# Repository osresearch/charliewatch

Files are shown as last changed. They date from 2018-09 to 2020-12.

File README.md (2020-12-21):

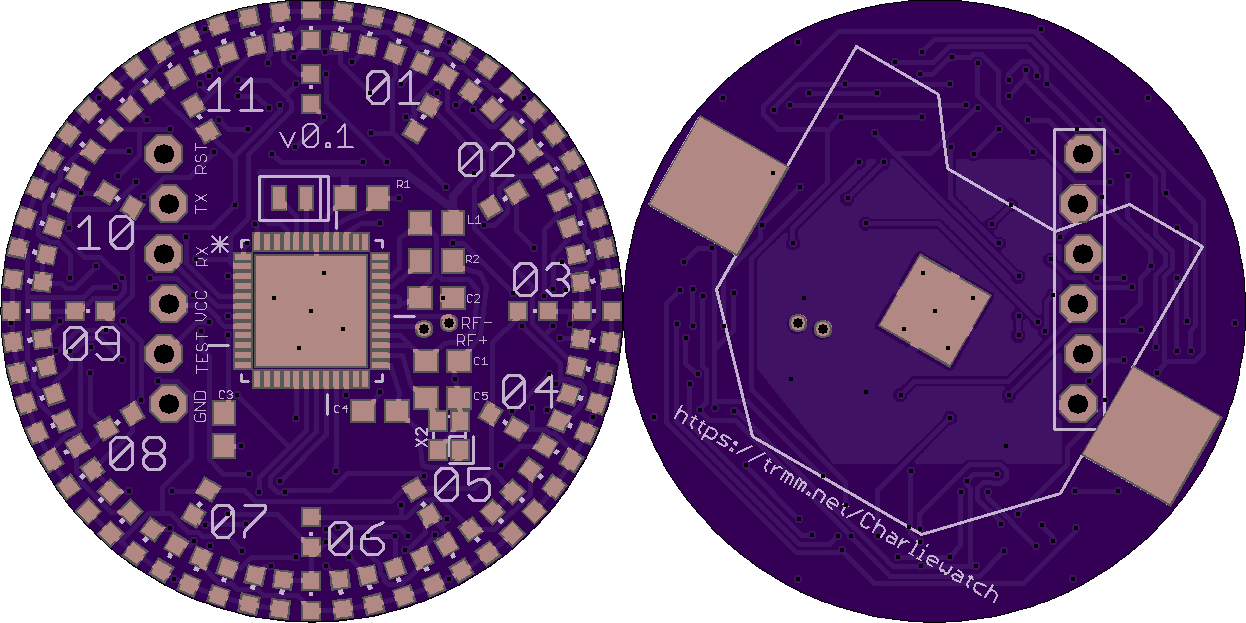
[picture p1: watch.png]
Watch rendering


"Analog" watch with 60+12 Charlieplexed LEDs. Based on Travis Goodspeed's
GoodWatch21 schematic, using the CC430F5137IRGZR CPU, which doesn't
have the LCD controller of the CC430F6xxx in the GoodWatch. There are
also pads for a six pin EZfet cable with pogopins for programming or
serial communication.

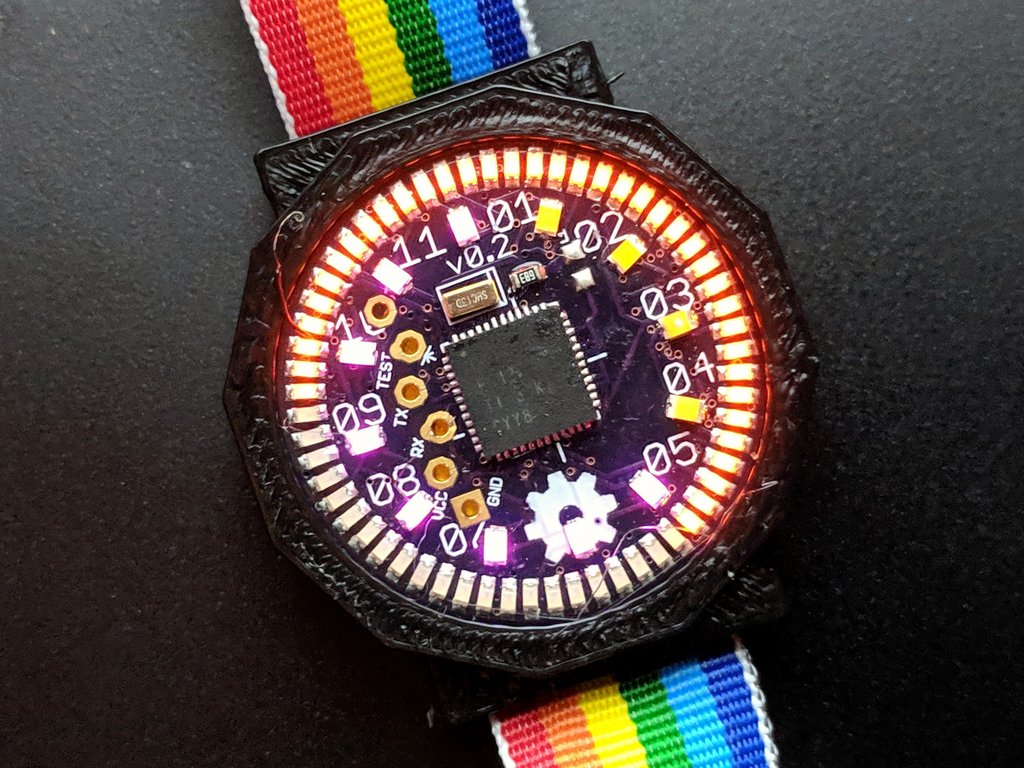
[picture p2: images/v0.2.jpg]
v0.2 board, populated

v0.2 works, although it has no radio parts.  It is exactly 1 square inch
of PCB and should fit in a 38mm or 36mm case.

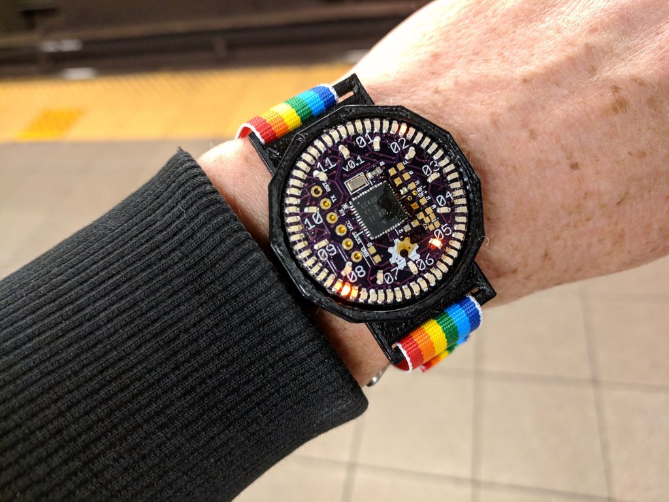
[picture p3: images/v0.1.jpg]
v0.1 board

v0.1 works, although the radio parts have not been tested.  It is a slightly
larger board and fits in a 40mm case.

[Charliewtch schematic](datasheets/charliewatch.pdf)

Building the firmware
-----

Note: some other system packages (boost libraries?) might also be needed.

First, get the toolchain (msp430-gcc):

    sudo apt install gcc-msp430 mspdebug

Then the all-important lib file (from https://www.ti.com/tool/MSPDS):

    sudo apt install libhidapi-dev
    mkdir MSPDebugStack
    wget https://software-dl.ti.com/msp430/msp430_public_sw/mcu/msp430/MSPDS/3_15_1_001/export/MSPDebugStack_OS_Package_3_15_1_1.zip

Copy in the hidapi header (WTFBBQ):

    cp /usr/include/hidapi/hidapi.h ThirdParty/include/

Copy the following into a file 'hidapi.patch', so we can use the system hidapi library:

    --- Makefile    2020-12-18 18:01:18.602942502 +0100
    +++ Makefile.new    2020-12-18 18:02:58.472096541 +0100
    @@ -123,7 +123,7 @@
     OBJS := $(patsubst %.cpp, %.o, $(SRC))
    
     all: $(BSLLIB) $(OBJS)
    -   $(CXX) $(CXXFLAGS) -shared $(OUTNAME)$(OUTPUT) -o $(OUTPUT) $(OBJS) $(HIDOBJ) $(LIBDIRS) $(BSTATIC) $(STATIC_LIBS) $(BDYNAMIC) $(LIBS)
    +   $(CXX) $(CXXFLAGS) -shared $(OUTNAME)$(OUTPUT) -o $(OUTPUT) $(OBJS) -lhidapi-libusb $(LIBDIRS) $(BSTATIC) $(STATIC_LIBS) $(BDYNAMIC) $(LIBS)
        rm -f $(STATICOUTPUT).a
        ar -rs $(STATICOUTPUT).a $(OBJS)

Then apply and make:

    patch < hidapi.patch
    make

Finally, build and flash the firmware:

    git clone https://github.com/osresearch/charliewatch.git
    cd charliewatch/firmware
    make
    export LD_LIBRARY_PATH=$LD_LIBRARY_PATH:`pwd`../../MSPDebugStack/
    mspdebug tilib "prog charliewatch.elf"

Programming cable
-----

From the top of the v0.1 board:
* RST / TDIO
* RXD on programmer
* TXD on programmer
* VCC
* TST / TCK
* GND

v0.2:
* greem
* white
* blue
* purple
* gray
* black

There is also a four-wire setup that might simplify the wiring.
Travis documents it and the power consumption here:
https://github.com/travisgoodspeed/goodwatch/wiki/EnergyTrace

Bricked Launchpad
-----

If you brick your launchpad by running Energia under Linux, it will no
longer program the Charliewatch.  The other weirdness is that `tilib`
can detect the device, but can't write to it unless run as root.

Energy Trace
----
* `libmsp430.so`: https://dlbeer.co.nz/articles/slac460y/index.html
* https://github.com/carrotIndustries/energytrace-util
* Have to update path to `MSP430.h` from the `slac/DLL430_v3/include` directory

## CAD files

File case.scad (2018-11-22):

// v0.1 board is 0.622" radius
// v0.2 board is 0.5642" radius (1 square inch)

// 3d printed bracelet (default is nato strap)
linked_bracelet = 0;

// play between the links
link_play = 1.4;

// horizontal play between the teeth
teeth_play = 0.2;

// extra spacing for the dial
dial_play = 0.4;

band_height = 4;
pin_ratio = 3/5;


module link(w,d,h,w2, last=0, first=0)
{
	render() difference() {
		intersection() {
			translate([0,0,-h/2-1])
			linear_extrude(height=h+2)
			polygon([
				[-w2/2,-(d+h+(last?h:0))/2],
				[+w2/2,-(d+h+(last?h:0))/2],
				[+w/2,+(d+h)/2],
				[-w/2,+(d+h)/2],
			]);
		union() {

			cube([w2 > w ? w2 : w,d,h], center=true);

			// positive rounded edge A1, length w2
			translate([0,d/2,0])
			rotate([0,90,0]) 
			cylinder(d=h, h=w, $fn=32, center=true);

			// positive rounded edge B2
			translate([0,-d/2,0])
			rotate([0,90,0]) 
			cylinder(d=h, h=w2, $fn=32, center=true);

			// last one has a square clasp
			if(last)
			{
				translate([0,-h,0])
				cube([w/3-2*teeth_play,h,h], center=true);

				translate([0,-h*3/2,0])
				rotate([0,90,0]) 
				cylinder(d=h, h=w/3-2*teeth_play, $fn=32, center=true);
			}
		}
		}

		// negative large rounded edge B1
		translate([w2/3/2-teeth_play,-d/2,0])
		rotate([0,90,0]) 
		cylinder(d=h+link_play, h=w2/3+4, $fn=32);

		translate([-w2/3/2+teeth_play,-d/2,0])
		rotate([0,-90,0]) 
		cylinder(d=h+link_play, h=w2/3+4, $fn=32);

		// negative large rounded edge A2
		translate([0,d/2,0])
		rotate([0,90,0]) 
		cylinder(d=h+link_play, h=w2/3+2*teeth_play, $fn=32, center=true);

		// pin hole
		translate([0,-d/2,0])
		rotate([0,90,0]) 
		cylinder(d=h*pin_ratio, h=w+2, $fn=32, center=true);

		// if this is the last one,
		if(last) {
			// make the hole open on the bottom
			translate([0,-d/2,-1])
			//rotate([20,0,0])
			cube([w,h*pin_ratio,h/2+1], center=true);

			translate([0,-d/2-h/3,0])
			rotate([0,90,0]) 
			cylinder(d=h*pin_ratio, h=w+2, $fn=32, center=true);

			translate([0,-d/2-h/3/2,0])
			//rotate([20,0,0])
			cube([w,h*pin_ratio,h*pin_ratio], center=true);
		}

		if (first) {
			// and make the clasp side even large
			translate([0,+h/3,-1])
			cube([w2/3+2*teeth_play,h,h+2], center=true);
		}


		// maybe add some fun patterns
		if(0) {
		translate([w*1/6,d/2+h/4,-1]) cylinder(d=w/4, h=h+2, $fn=7);
		translate([w*3/6,d/2-h/4,-1]) cylinder(d=w/4, h=h+2, $fn=7);
		translate([w*5/6,d/2+h/4,-1]) cylinder(d=w/4, h=h+2, $fn=7);
		}
	}

	// pin
	translate([0,d/2,0])
	rotate([0,90,0])
	cylinder(d=h*pin_ratio-2*teeth_play, h=w-2, $fn=32, center=true);
}

module case(dial,lug_offset,band_width,height)
{
render() difference()
{
	union() {
		intersection() {
		// 12-sided outside
		rotate([0,0,360/12/2]) cylinder(r=dial+2.5, h=height, $fn=12);
		// round off the corners slightly
		translate([0,0,-1]) cylinder(r=dial+2.5-0.1, h=height+2, $fn=180);
		// and round off the top slightly
		sphere(r=dial+2.5+0.8, $fn=60);
		}


		// lug
		if(linked_bracelet)
		{
			translate([+lug_offset+1,0,band_height/2])
			rotate([0,0,90])
			link(band_width, 8, band_height, w2=band_width-1);

			translate([-lug_offset-2,0,band_height/2])
			rotate([0,0,90])
			link(band_width, 8, band_height, w2=band_width);

			translate([-lug_offset,0,band_height/2])
			rotate([0,0,90])
			cube([band_width,5,band_height], center=true);
		} else {
			translate([+lug_offset,0,band_height/2])
			rotate([0,0,90])
			cube([band_width+2,8,band_height], center=true);

			translate([-lug_offset,0,band_height/2])
			rotate([0,0,90])
			cube([band_width+2,8,band_height], center=true);
		}

		// bump for button
		//translate([0,dial,height/4]) cylinder(r=3, h=height/2, $fn=30);
	}


	// tapered cylinder inside
	translate([0,0,height-1]) cylinder(r1=dial+dial_play, r2=dial-dial_play, h=1.1, $fn=60);

	// cutout for button
	translate([0,dial,1.5]) cylinder(r=3-0.1, h=2.5, $fn=30);

	// larger inside cylinder
	cylinder(r=dial+dial_play, h=height-1, $fn=180);

	// slot for strap if not using a linked bracelet
	if (!linked_bracelet)
	{
		translate([-14,0,1.5]) rotate([0,+30,0])
		cube([20,band_width+0.2,2.5], center=true);

		translate([+14,0,1.5]) rotate([0,-30,0])
		cube([20,band_width+0.2,2.5], center=true);
	}
}
}


// v0.1 case
if(0)
translate([0,25,0]) case(
	dial=0.622 * 25.4,
	lug_offset = 16,
	band_width = 22.2,
	height=8
);


// v0.2 case
band_width = 18;
band_length = 8;
band_count = round(160 / band_length / 2);

case(
	dial = 29/2, // 0.5642 * 25.4,
	lug_offset = 14,
	band_width = linked_bracelet ? band_width + band_count*0.5 : band_width,
	height = 7.5
);

if(link_braclet)
{
	for(i=[1:band_count])
	{
		translate([-i*band_length-14-2,0,band_height/2])
		rotate([0,0,90])
		link(
			band_width+(band_count-i+1)*0.5,
			band_length,
			band_height,
			band_width+(band_count-i)*0.5,
			first=(i==band_count)
		);
	}

	if(1)
	for(i=[1:band_count-1])
	{
		translate([+i*band_length+14+1,0,band_height/2])
		rotate([0,0,90])
		link(
			band_width + (band_count-i)*0.5,
			band_length,
			band_height,
			band_width + (band_count-i-1)*0.5,
			last=(i==band_count-1)
		);
	}
}

%translate([0,20,0]) cube([190,1,1], center=true);

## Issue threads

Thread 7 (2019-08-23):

Charlieboard-bicolor brd file

salmansheikh, 2019-08-23:
Hello,

When I open it in Eagle, it says Dont forget change dimension circle to 0.5642. Do I need to modify the pcb? And when I uploaded the 2 layer board to osh-park, I got this. Is this okay to order and will work correctly?
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

pomeroyb, 2019-08-25:
I believe that the file you've uploaded won't work. You'll need to use either "routed.brd" or "routed-norf.brd" for a file that works I think.

Opening "charliewatch-bicolor.brd" shows that there are still a lot of airwires in that file. Looking at the photo you've attached -- it definitely looks like it's missing traces.

Disclaimer: I'm not the creator of these files, i've just been playing with them for the past day or so.

salmansheikh, 2019-08-25:
Oh no. I uploaded and ordered the board from osh-Park. Oh well $6.45 for 3
coasters. 😂. I will do it again.

On Sun, Aug 25, 2019 at 1:36 AM Brandon Pomeroy <notifications@github.com>
wrote:

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
--
Even a Smile is charity :)
- Prophet Muhammad

salmansheikh, 2019-08-25:
What is the difference between the routed and routed-norf in capability? Are you using any of the rf capabilities of the chip?

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

pomeroyb, 2019-08-26:
The routed version breaks out pins for the wireless antenna. The routed-norf version doesn’t, but they are otherwise identical iirc.

I’m not personally using any rf stuff in my version, I don’t think it’s that interesting. :)

salmansheikh, 2019-09-01:
The LEDS making the seconds or minutes vs hours look like 2 different sizes. Also, what are the crystal values..I don't see them on the schematic.

pomeroyb, 2019-09-01:
The LEDs on the routed boards are all 0603 surface mount LEDs. On the bicolor file, the minute LEDs are
https://www.digikey.com/product-detail/en/kingbright/APHB1608SYKSURKC/754-1855-1-ND/4977027

The crystal used is (I believe)
https://www.digikey.com/product-detail/en/iqd-frequency-products/LFXTAL050789REEL/1923-1583-1-ND/8634325

@osresearch could you confirm that that is the proper crystal?

MarkJB, 2019-09-23:
I've ordered some PCBs as a fun group build for the local maker space and am starting to order the components but I'm also stuck on the xtal and would appreciate confirmation of the part used.

salmansheikh, 2019-09-25:
The crystal is in the email above but also available from Mouser at

https://www.mouser.com/ProductDetail/449-LFXTAL050789CUTT

And repeated here from the previous post by pomeroyb on this issue:

https://www.digikey.com/product-detail/en/iqd-frequency-products/LFXTAL050789REEL/1923-1583-1-ND/8634325

I found LEDs to be cheaper at mouser.  I have 3 components here (LED, chip and crystal). Need to get the rest of the passives from the schematic and add them. Price is around $38 for 3 so far, it was like $58 for equivalent from digikey using inolux LEDs..

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

salmansheikh, 2019-09-25:
Also, there is no part value for C1-C4 (size 0603 is all that is shown in the charliewatch.sch which I think corresponds with routed.brd.
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

osresearch, 2019-09-25:
Sorry for not catching this one earlier -- I just received a notification for the recent comment, but had missed the earlier questions.

The bi-color board is not finished.  I haven't found decent bicolor 0603 LEDs, so that part of the project stopped.  The routed-norf is the most recent and works well.

The crystal I used is https://www.digikey.com/product-detail/en/ABS07-120-32.768KHZ-T/535-11937-1-ND/3724046

And the orange LEDs are 2V forward voltage, 160 millicandela https://www.digikey.com/product-detail/en/LO+Q976-PS-25-0-20-R18/475-2486-1-ND/1802613

I'm a horrible EE and there are no caps on the board, just a pull up resistor on the reset line.

salmansheikh, 2019-09-25:
I had the routed.brd built. How is that different from the norf version?

osresearch, 2019-09-25:
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

The v0.1 (`routed.brd`) is slightly larger than the v0.2 (`routed-norf.brd`) and doesn't have a button on the bottom.  The RF parts were never assembled or tested.

For time and mode setting you can use a jumper wire on the RX pin.  There is a define in `button.c` to remap it as the input button: https://github.com/osresearch/charliewatch/blob/master/firmware/button.c#L11

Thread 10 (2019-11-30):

Build errors: BUILDTIME & BUILDSEC undeclared here (not in function)

MarkJB, 2019-11-30:
I'm seeing build errors in the latest Code Composer Studio and the GNU v8.3.0.16 compiler on Win10.

I'll keep trying to figure this out, but any suggestions or pointers appreciated.

Build output:

```
**** Build of configuration Release__GNU for project Charliewatch ****

"D:\\Apps\\ti\\cc920\\ccs\\utils\\bin\\gmake" -k -j 8 all -O

Building file: "../buildtime.c"
Invoking: GNU Compiler
"D:/Apps/ti/cc920/ccs/tools/compiler/msp430-gcc-8.3.0.16_win32/bin/msp430-elf-gcc-8.3.0.exe" -c -mmcu=cc430f5137 -mhwmult=f5series -I"D:/Apps/ti/cc920/ccs/ccs_base/msp430/include_gcc" -I"D:/Code/charliewatch/firmware" -I"D:/Apps/ti/cc920/ccs/tools/compiler/msp430-gcc-8.3.0.16_win32/msp430-elf/include" -Os -Wall -MMD -MP -MF"buildtime.d" -MT"buildtime.o"   -o"buildtime.o" "../buildtime.c"
subdir_rules.mk:9: recipe for target 'buildtime.o' failed
../buildtime.c:4:33: error: 'BUILDTIME' undeclared here (not in a function)
 const uint8_t romsavetime[] = { BUILDTIME };
                                 ^~~~~~~~~
../buildtime.c:5:28: error: 'BUILDSEC' undeclared here (not in a function)
 const uint32_t buildtime = BUILDSEC;
                            ^~~~~~~~
../buildtime.c:5:28: warning: initialization of 'uint32_t' {aka 'const long unsigned int'} from 'const uint8_t *' {aka 'const unsigned char *'} makes integer from pointer without a cast [-Wint-conversion]
../buildtime.c:5:28: error: initializer element is not constant
gmake: *** [buildtime.o] Error 1
Building file: "../adc.c"
Invoking: GNU Compiler
"D:/Apps/ti/cc920/ccs/tools/compiler/msp430-gcc-8.3.0.16_win32/bin/msp430-elf-gcc-8.3.0.exe" -c -mmcu=cc430f5137 -mhwmult=f5series -I"D:/Apps/ti/cc920/ccs/ccs_base/msp430/include_gcc" -I"D:/Code/charliewatch/firmware" -I"D:/Apps/ti/cc920/ccs/tools/compiler/msp430-gcc-8.3.0.16_win32/msp430-elf/include" -Os -Wall -MMD -MP -MF"adc.d" -MT"adc.o"   -o"adc.o" "../adc.c"
Finished building: "../adc.c"

Building file: "../button.c"
Invoking: GNU Compiler
"D:/Apps/ti/cc920/ccs/tools/compiler/msp430-gcc-8.3.0.16_win32/bin/msp430-elf-gcc-8.3.0.exe" -c -mmcu=cc430f5137 -mhwmult=f5series -I"D:/Apps/ti/cc920/ccs/ccs_base/msp430/include_gcc" -I"D:/Code/charliewatch/firmware" -I"D:/Apps/ti/cc920/ccs/tools/compiler/msp430-gcc-8.3.0.16_win32/msp430-elf/include" -Os -Wall -MMD -MP -MF"button.d" -MT"button.o"   -o"button.o" "../button.c"
Finished building: "../button.c"

Building file: "../animation.c"
Invoking: GNU Compiler
"D:/Apps/ti/cc920/ccs/tools/compiler/msp430-gcc-8.3.0.16_win32/bin/msp430-elf-gcc-8.3.0.exe" -c -mmcu=cc430f5137 -mhwmult=f5series -I"D:/Apps/ti/cc920/ccs/ccs_base/msp430/include_gcc" -I"D:/Code/charliewatch/firmware" -I"D:/Apps/ti/cc920/ccs/tools/compiler/msp430-gcc-8.3.0.16_win32/msp430-elf/include" -Os -Wall -MMD -MP -MF"animation.d" -MT"animation.o"   -o"animation.o" "../animation.c"
Finished building: "../animation.c"

Building file: "../clockset.c"
Invoking: GNU Compiler
"D:/Apps/ti/cc920/ccs/tools/compiler/msp430-gcc-8.3.0.16_win32/bin/msp430-elf-gcc-8.3.0.exe" -c -mmcu=cc430f5137 -mhwmult=f5series -I"D:/Apps/ti/cc920/ccs/ccs_base/msp430/include_gcc" -I"D:/Code/charliewatch/firmware" -I"D:/Apps/ti/cc920/ccs/tools/compiler/msp430-gcc-8.3.0.16_win32/msp430-elf/include" -Os -Wall -MMD -MP -MF"clockset.d" -MT"clockset.o"   -o"clockset.o" "../clockset.c"
Finished building: "../clockset.c"

Building file: "../led.c"
Invoking: GNU Compiler
"D:/Apps/ti/cc920/ccs/tools/compiler/msp430-gcc-8.3.0.16_win32/bin/msp430-elf-gcc-8.3.0.exe" -c -mmcu=cc430f5137 -mhwmult=f5series -I"D:/Apps/ti/cc920/ccs/ccs_base/msp430/include_gcc" -I"D:/Code/charliewatch/firmware" -I"D:/Apps/ti/cc920/ccs/tools/compiler/msp430-gcc-8.3.0.16_win32/msp430-elf/include" -Os -Wall -MMD -MP -MF"led.d" -MT"led.o"   -o"led.o" "../led.c"
Finished building: "../led.c"

Building file: "../main.c"
Invoking: GNU Compiler
"D:/Apps/ti/cc920/ccs/tools/compiler/msp430-gcc-8.3.0.16_win32/bin/msp430-elf-gcc-8.3.0.exe" -c -mmcu=cc430f5137 -mhwmult=f5series -I"D:/Apps/ti/cc920/ccs/ccs_base/msp430/include_gcc" -I"D:/Code/charliewatch/firmware" -I"D:/Apps/ti/cc920/ccs/tools/compiler/msp430-gcc-8.3.0.16_win32/msp430-elf/include" -Os -Wall -MMD -MP -MF"main.d" -MT"main.o"   -o"main.o" "../main.c"
Finished building: "../main.c"

Building file: "../power.c"
Invoking: GNU Compiler
"D:/Apps/ti/cc920/ccs/tools/compiler/msp430-gcc-8.3.0.16_win32/bin/msp430-elf-gcc-8.3.0.exe" -c -mmcu=cc430f5137 -mhwmult=f5series -I"D:/Apps/ti/cc920/ccs/ccs_base/msp430/include_gcc" -I"D:/Code/charliewatch/firmware" -I"D:/Apps/ti/cc920/ccs/tools/compiler/msp430-gcc-8.3.0.16_win32/msp430-elf/include" -Os -Wall -MMD -MP -MF"power.d" -MT"power.o"   -o"power.o" "../power.c"
Finished building: "../power.c"

Building file: "../rtc.c"
Invoking: GNU Compiler
"D:/Apps/ti/cc920/ccs/tools/compiler/msp430-gcc-8.3.0.16_win32/bin/msp430-elf-gcc-8.3.0.exe" -c -mmcu=cc430f5137 -mhwmult=f5series -I"D:/Apps/ti/cc920/ccs/ccs_base/msp430/include_gcc" -I"D:/Code/charliewatch/firmware" -I"D:/Apps/ti/cc920/ccs/tools/compiler/msp430-gcc-8.3.0.16_win32/msp430-elf/include" -Os -Wall -MMD -MP -MF"rtc.d" -MT"rtc.o"   -o"rtc.o" "../rtc.c"
Finished building: "../rtc.c"

Building file: "../ucs.c"
Invoking: GNU Compiler
"D:/Apps/ti/cc920/ccs/tools/compiler/msp430-gcc-8.3.0.16_win32/bin/msp430-elf-gcc-8.3.0.exe" -c -mmcu=cc430f5137 -mhwmult=f5series -I"D:/Apps/ti/cc920/ccs/ccs_base/msp430/include_gcc" -I"D:/Code/charliewatch/firmware" -I"D:/Apps/ti/cc920/ccs/tools/compiler/msp430-gcc-8.3.0.16_win32/msp430-elf/include" -Os -Wall -MMD -MP -MF"ucs.d" -MT"ucs.o"   -o"ucs.o" "../ucs.c"
Finished building: "../ucs.c"

Building file: "../stopwatch.c"
Invoking: GNU Compiler
"D:/Apps/ti/cc920/ccs/tools/compiler/msp430-gcc-8.3.0.16_win32/bin/msp430-elf-gcc-8.3.0.exe" -c -mmcu=cc430f5137 -mhwmult=f5series -I"D:/Apps/ti/cc920/ccs/ccs_base/msp430/include_gcc" -I"D:/Code/charliewatch/firmware" -I"D:/Apps/ti/cc920/ccs/tools/compiler/msp430-gcc-8.3.0.16_win32/msp430-elf/include" -Os -Wall -MMD -MP -MF"stopwatch.d" -MT"stopwatch.o"   -o"stopwatch.o" "../stopwatch.c"
Finished building: "../stopwatch.c"

Building file: "../rtcasm.S"
Invoking: GNU Compiler
"D:/Apps/ti/cc920/ccs/tools/compiler/msp430-gcc-8.3.0.16_win32/bin/msp430-elf-gcc-8.3.0.exe" -c -mmcu=cc430f5137 -mhwmult=f5series -I"D:/Apps/ti/cc920/ccs/ccs_base/msp430/include_gcc" -I"D:/Code/charliewatch/firmware" -I"D:/Apps/ti/cc920/ccs/tools/compiler/msp430-gcc-8.3.0.16_win32/msp430-elf/include" -Os -Wall -MMD -MP -MF"rtcasm.d" -MT"rtcasm.o" -x assembler-with-cpp  -o"rtcasm.o" "../rtcasm.S"
../rtcasm.S: Assembler messages:
../rtcasm.S:60: Warning: a NOP might be needed here, before an interrupt enable instruction
../rtcasm.S:61: Warning: a NOP might be needed here, after an interrupt enable instruction
../rtcasm.S:85: Warning: a NOP might be needed here, after an interrupt enable instruction
../rtcasm.S:120: Warning: a NOP might be needed here, after an interrupt enable instruction
../rtcasm.S:141: Warning: a NOP might be needed here, after an interrupt enable instruction
../rtcasm.S:164: Warning: a NOP might be needed here, after an interrupt enable instruction
../rtcasm.S:185: Warning: a NOP might be needed here, after an interrupt enable instruction
../rtcasm.S:208: Warning: a NOP might be needed here, after an interrupt enable instruction
Finished building: "../rtcasm.S"

gmake: Target 'all' not remade because of errors.

**** Build Finished ****
```

MarkJB, 2019-12-01:
I guess this is because Code Composer Studio is creating its own makefile and ignoring the one in the src dir.

I downloaded the standalone GCC compiler (http://www.ti.com/tool/MSP430-GCC-OPENSOURCE) and gnuwin32 tools for make.

Running 'make' in the src dir, it sits there waiting.

I'm guessing its waiting for me to enter a datetime. Trying to work out what that should be now...

MarkJB, 2019-12-01:
I'm guessing this is meant to be run in Linux.

```
mark@MARK-HPENVYX360:/mnt/d/Code/charliewatch/firmware$ make
msp430-gcc -mmcu=cc430f5137 -Wall -Werror -I. -Os -MMD -MF .main.o.d -DBUILDTIME=19,12,101-100,112-100,135-100,100-100 -DBUILDSEC=1575203700    -c -o main.o main.c
main.c:9:10: fatal error: msp430.h: No such file or directory
 #include <msp430.h>
          ^~~~~~~~~~
compilation terminated.
<builtin>: recipe for target 'main.o' failed
make: *** [main.o] Error 1
```

MarkJB, 2020-01-14:
I was able to get this working in Windows & Code Composer Studio https://github.com/MarkJB/charliewatch/commit/241307116b79f590d2357c6dfa740004f2cb064c

Closed 2019-12-01.

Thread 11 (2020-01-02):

Animation displayed on power

MarkJB, 2020-01-02:

MarkJB, 2020-01-03:
Have been stepping thru the code and it seems to be getting stuck in ucs.c in the xtal stabilization do loop.

Have commented out the 'Loop until XT1 & DCO stabilizes' do while loop and it now starts up on battery.

Will have a read thru the datasheet and see if I can figure out if this is bad.

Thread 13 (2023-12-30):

0805 LEDs are backwards in schematic compared to circuitpainter output (v2.1 board)

osresearch, 2023-12-30:
The hour LEDs are the wrong way around in the circuit painter output; the cathode and anode needs to be swapped.

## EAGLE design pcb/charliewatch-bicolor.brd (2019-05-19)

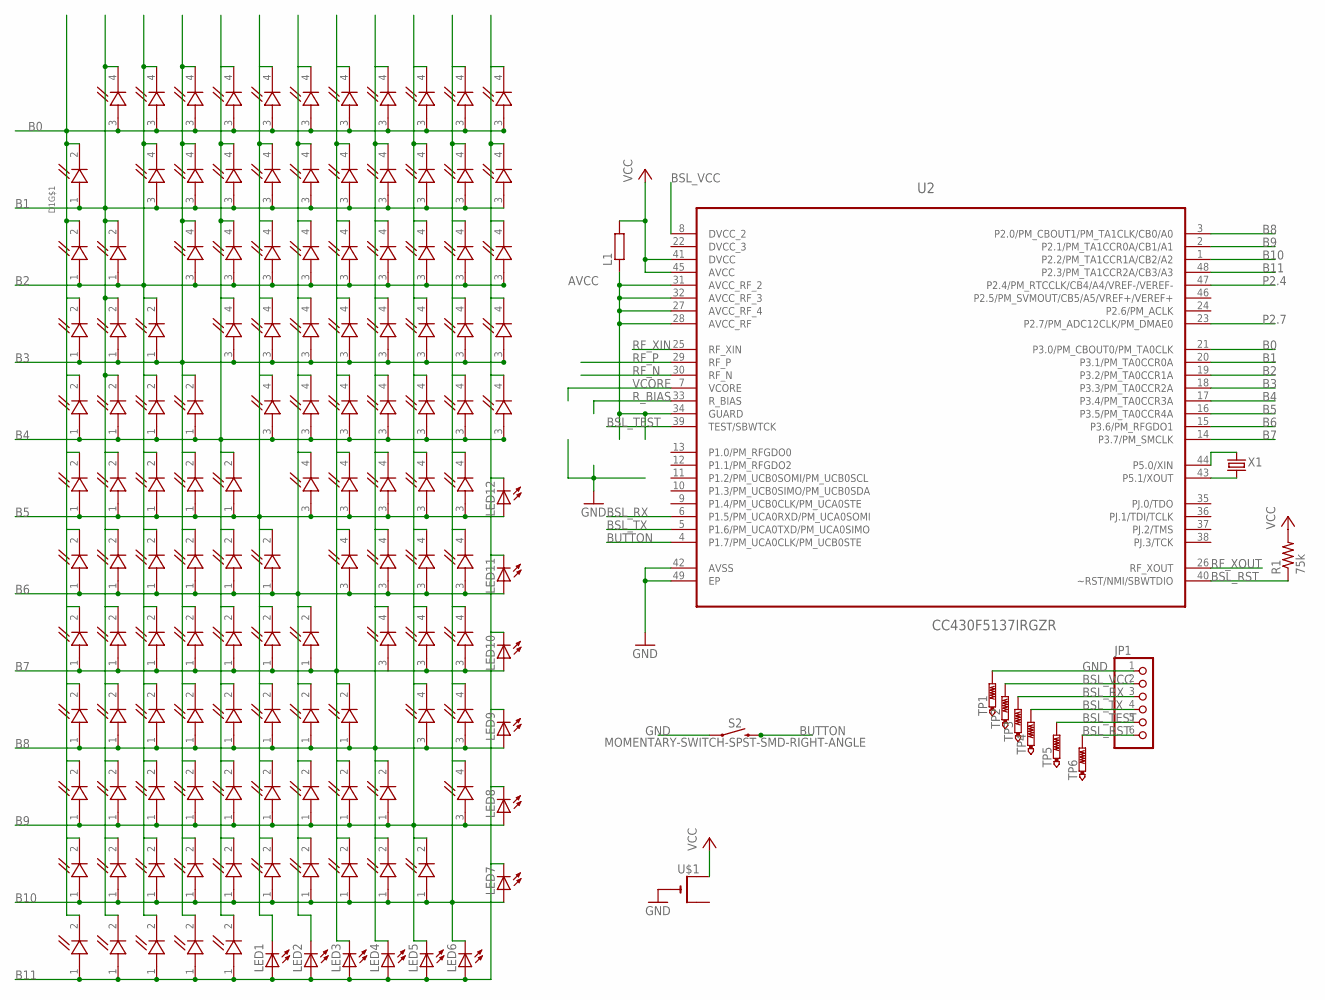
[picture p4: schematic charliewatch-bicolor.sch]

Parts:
D1, D2, D3, D4, D5, D6, D7, D8, D9, D10, D11, D12, D13, D14, D15, D16, D17, D18, D19, D20, D21, D22, D23, D24, D25, D26, D27, D28, D29, D30, D31, D32, D33, D34, D35, D36, D37, D38, D39, D40, D41, D42, D43, D44, D45, D46, D47, D48, D49, D50, D51, D52, D53, D54, D55, D56, D57, D58, D59, D60: APHB1608SYKSURKC; LED_APHB1608SYKSURKC
JP1: PINHD-1X6LOCK; 1X06-BIGLOCK
L1: R-EU_R0603; R0603
LED1, LED2, LED3, LED4, LED5, LED6, LED7, LED8, LED9, LED10, LED11, LED12: LEDCHIPLED_0805; CHIPLED_0805
R1: 75k; R0402
S2: MOMENTARY-SWITCH-SPST-SMD-RIGHT-ANGLE; TACTILE_SWITCH_SMD_RIGHT_ANGLE
TP1: PTR1TP10SQ; TP10SQ
TP2, TP3, TP4, TP5, TP6: PTR1TP10R; TP10R
U2: CC430F5137IRGZR; QFN50P700X700X100-49N
U$1: CR2032THM; CR2032-THRU
X1: CRYSTALS-NOGND-IQXC-25; 2.0X1.2-2PAD

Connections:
AVCC: L1.1, U2.27 (AVCC_RF_4), U2.28 (AVCC_RF), U2.31 (AVCC_RF_2), U2.32 (AVCC_RF_3), U2.34 (GUARD)
B0: D1.2 (Y_C), D1.3 (R_A), D2.2 (Y_C), D2.3 (R_A), D3.2 (Y_C), D3.3 (R_A), D5.2 (Y_C), D5.3 (R_A), D7.2 (Y_C), D7.3 (R_A), D10.2 (Y_C), D10.3 (R_A), D13.2 (Y_C), D13.3 (R_A), D17.2 (Y_C), D17.3 (R_A), D21.2 (Y_C), D21.3 (R_A), D26.2 (Y_C), D26.3 (R_A), D31.2 (Y_C), D31.3 (R_A), U2.21 (P3.0/PM_CBOUT0/PM_TA0CLK)
B1: D1.1 (Y_A), D1.4 (R_C), D4.2 (Y_C), D4.3 (R_A), D6.2 (Y_C), D6.3 (R_A), D8.2 (Y_C), D8.3 (R_A), D11.2 (Y_C), D11.3 (R_A), D14.2 (Y_C), D14.3 (R_A), D18.2 (Y_C), D18.3 (R_A), D22.2 (Y_C), D22.3 (R_A), D27.2 (Y_C), D27.3 (R_A), D32.2 (Y_C), D32.3 (R_A), D37.2 (Y_C), D37.3 (R_A), U2.20 (P3.1/PM_TA0CCR0A)
B2: D2.1 (Y_A), D2.4 (R_C), D4.1 (Y_A), D4.4 (R_C), D9.2 (Y_C), D9.3 (R_A), D12.2 (Y_C), D12.3 (R_A), D15.2 (Y_C), D15.3 (R_A), D19.2 (Y_C), D19.3 (R_A), D23.2 (Y_C), D23.3 (R_A), D28.2 (Y_C), D28.3 (R_A), D33.2 (Y_C), D33.3 (R_A), D38.2 (Y_C), D38.3 (R_A), D42.2 (Y_C), D42.3 (R_A), U2.19 (P3.2/PM_TA0CCR1A)
B3: D3.1 (Y_A), D3.4 (R_C), D6.1 (Y_A), D6.4 (R_C), D9.1 (Y_A), D9.4 (R_C), D16.2 (Y_C), D16.3 (R_A), D20.2 (Y_C), D20.3 (R_A), D24.2 (Y_C), D24.3 (R_A), D29.2 (Y_C), D29.3 (R_A), D34.2 (Y_C), D34.3 (R_A), D39.2 (Y_C), D39.3 (R_A), D43.2 (Y_C), D43.3 (R_A), D47.2 (Y_C), D47.3 (R_A), U2.18 (P3.3/PM_TA0CCR2A)
B4: D5.1 (Y_A), D5.4 (R_C), D8.1 (Y_A), D8.4 (R_C), D12.1 (Y_A), D12.4 (R_C), D16.1 (Y_A), D16.4 (R_C), D25.2 (Y_C), D25.3 (R_A), D30.2 (Y_C), D30.3 (R_A), D35.2 (Y_C), D35.3 (R_A), D40.2 (Y_C), D40.3 (R_A), D44.2 (Y_C), D44.3 (R_A), D48.2 (Y_C), D48.3 (R_A), D51.2 (Y_C), D51.3 (R_A), U2.17 (P3.4/PM_TA0CCR3A)
B5: D7.1 (Y_A), D7.4 (R_C), D11.1 (Y_A), D11.4 (R_C), D15.1 (Y_A), D15.4 (R_C), D20.1 (Y_A), D20.4 (R_C), D25.1 (Y_A), D25.4 (R_C), D36.2 (Y_C), D36.3 (R_A), D41.2 (Y_C), D41.3 (R_A), D45.2 (Y_C), D45.3 (R_A), D49.2 (Y_C), D49.3 (R_A), D52.2 (Y_C), D52.3 (R_A), LED1.C, LED12.A, U2.16 (P3.5/PM_TA0CCR4A)
B6: D10.1 (Y_A), D10.4 (R_C), D14.1 (Y_A), D14.4 (R_C), D19.1 (Y_A), D19.4 (R_C), D24.1 (Y_A), D24.4 (R_C), D30.1 (Y_A), D30.4 (R_C), D36.1 (Y_A), D36.4 (R_C), D46.2 (Y_C), D46.3 (R_A), D50.2 (Y_C), D50.3 (R_A), D53.2 (Y_C), D53.3 (R_A), D56.2 (Y_C), D56.3 (R_A), LED2.C, LED11.A, U2.15 (P3.6/PM_RFGDO1)
B7: D13.1 (Y_A), D13.4 (R_C), D18.1 (Y_A), D18.4 (R_C), D23.1 (Y_A), D23.4 (R_C), D29.1 (Y_A), D29.4 (R_C), D35.1 (Y_A), D35.4 (R_C), D41.1 (Y_A), D41.4 (R_C), D46.1 (Y_A), D46.4 (R_C), D54.2 (Y_C), D57.2 (Y_C), D57.3 (R_A), D59.2 (Y_C), D59.3 (R_A), LED10.A, U2.14 (P3.7/PM_SMCLK)
B8: D17.1 (Y_A), D17.4 (R_C), D22.1 (Y_A), D22.4 (R_C), D28.1 (Y_A), D28.4 (R_C), D34.1 (Y_A), D34.4 (R_C), D40.1 (Y_A), D40.4 (R_C), D45.1 (Y_A), D45.4 (R_C), D50.1 (Y_A), D50.4 (R_C), D54.1 (Y_A), D54.4 (R_C), D55.2 (Y_C), D55.3 (R_A), D60.2 (Y_C), D60.3 (R_A), LED9.A, U2.3 (P2.0/PM_CBOUT1/PM_TA1CLK/CB0/A0)
B9: D21.1 (Y_A), D21.4 (R_C), D27.1 (Y_A), D27.4 (R_C), D33.1 (Y_A), D33.4 (R_C), D39.1 (Y_A), D39.4 (R_C), D44.1 (Y_A), D44.4 (R_C), D49.1 (Y_A), D49.4 (R_C), D53.1 (Y_A), D53.4 (R_C), D57.1 (Y_A), D57.4 (R_C), D58.2 (Y_C), D58.3 (R_A), D60.1 (Y_A), D60.4 (R_C), LED8.A, U2.2 (P2.1/PM_TA1CCR0A/CB1/A1)
B10: D26.1 (Y_A), D26.4 (R_C), D32.1 (Y_A), D32.4 (R_C), D38.1 (Y_A), D38.4 (R_C), D43.1 (Y_A), D43.4 (R_C), D48.1 (Y_A), D48.4 (R_C), D52.1 (Y_A), D52.4 (R_C), D55.1 (Y_A), D55.4 (R_C), D56.1 (Y_A), D56.4 (R_C), D58.1 (Y_A), D58.4 (R_C), D59.1 (Y_A), D59.4 (R_C), LED7.A, U2.1 (P2.2/PM_TA1CCR1A/CB2/A2)
B11: D31.1 (Y_A), D31.4 (R_C), D37.1 (Y_A), D37.4 (R_C), D42.1 (Y_A), D42.4 (R_C), D47.1 (Y_A), D47.4 (R_C), D51.1 (Y_A), D51.4 (R_C), LED1.A, LED2.A, LED3.A, LED4.A, LED5.A, LED6.A, U2.48 (P2.3/PM_TA1CCR2A/CB3/A3)
BSL_RST: JP1.6, R1.1, TP6.TP, U2.40 (~RST/NMI/SBWTDIO)
BSL_RX: JP1.3, TP3.TP, U2.6 (P1.5/PM_UCA0RXD/PM_UCA0SOMI)
BSL_TEST: JP1.5, TP5.TP, U2.39 (TEST/SBWTCK)
BSL_TX: JP1.4, TP4.TP, U2.5 (P1.6/PM_UCA0TXD/PM_UCA0SIMO)
BSL_VCC: JP1.2, TP2.TP, U2.8 (DVCC_2)
BUTTON: S2.2, U2.4 (P1.7/PM_UCA0CLK/PM_UCB0STE)
DVCC_3: U2.22 (DVCC_3)
GND: JP1.1, S2.1, TP1.TP, U2.42 (AVSS), U2.49 (EP), U$1.-
P2.4: U2.47 (P2.4/PM_RTCCLK/CB4/A4/VREF-/VEREF-)
P2.7: U2.23 (P2.7/PM_ADC12CLK/PM_DMAE0)
RF_N: U2.30 (RF_N)
RF_P: U2.29 (RF_P)
RF_XIN: U2.25 (RF_XIN)
RF_XOUT: U2.26 (RF_XOUT)
R_BIAS: U2.33 (R_BIAS)
VCC: L1.2, R1.2, U2.41 (DVCC), U2.45 (AVCC), U$1.+1 (+)
VCORE: U2.7 (VCORE)
XIN: U2.44 (P5.0/XIN), X1.2
XOUT: U2.43 (P5.1/XOUT), X1.1

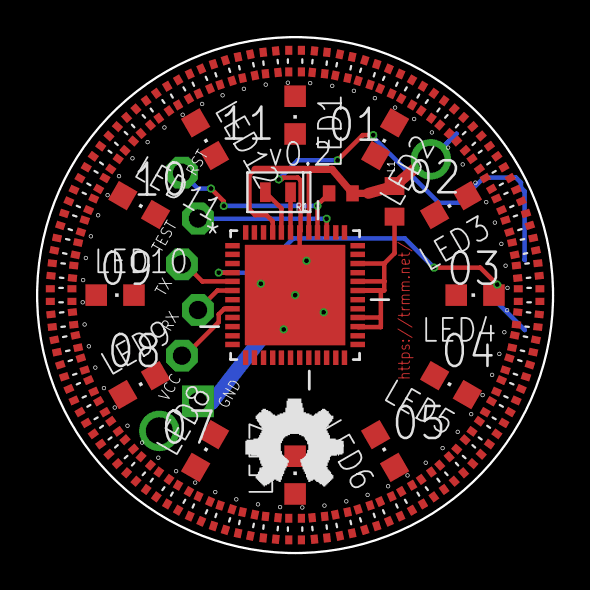
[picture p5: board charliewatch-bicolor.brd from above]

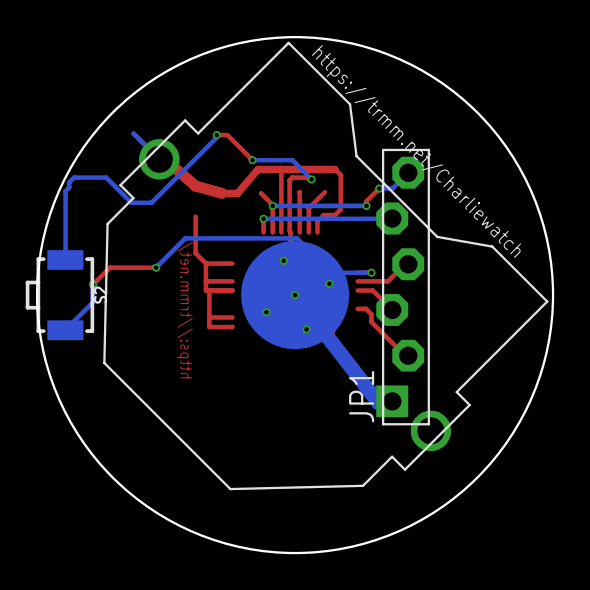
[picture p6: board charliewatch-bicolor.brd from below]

Board: 2 copper layers, 28.7 x 28.7 mm, 85 parts (3 on the bottom side), 23 nets.

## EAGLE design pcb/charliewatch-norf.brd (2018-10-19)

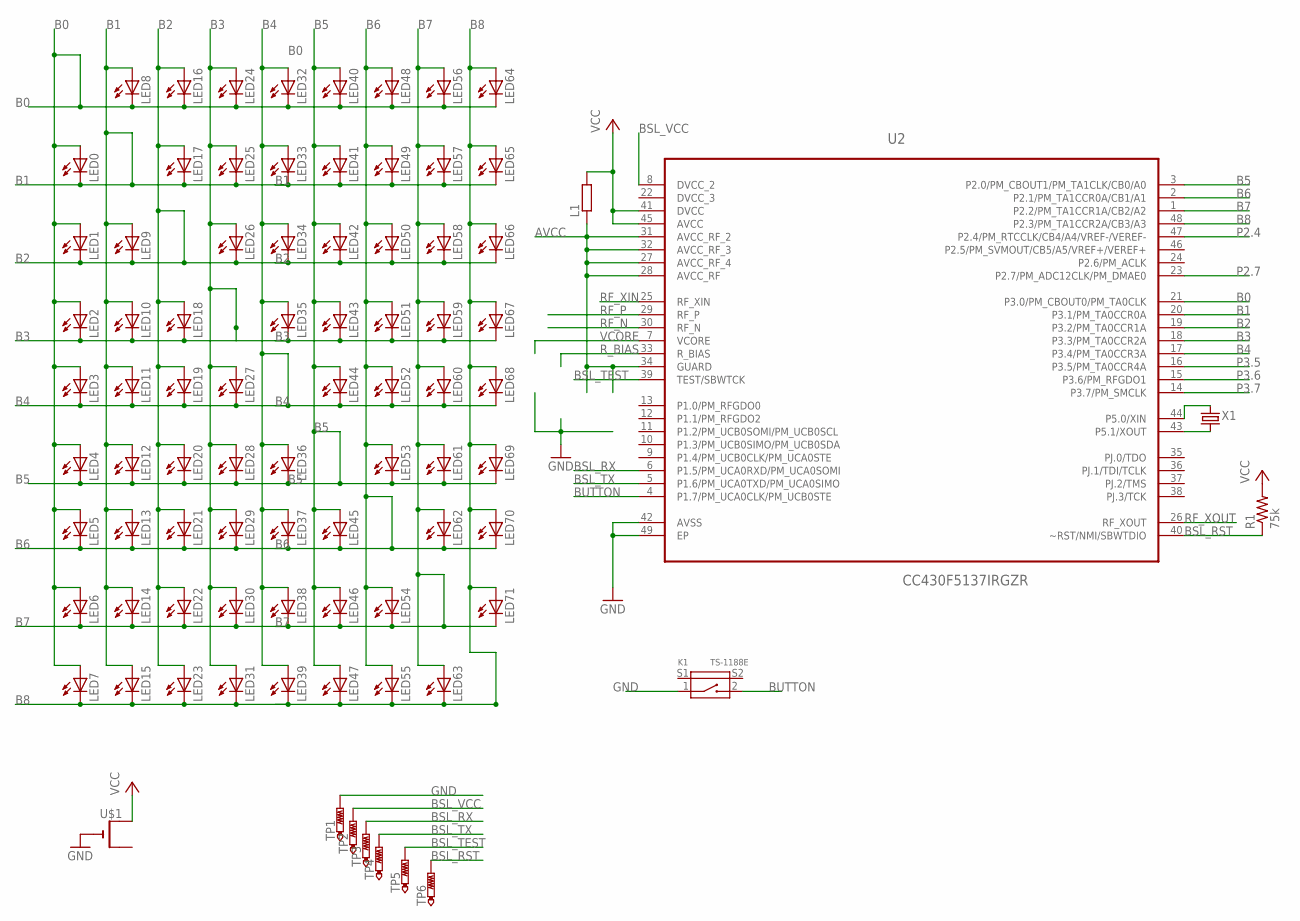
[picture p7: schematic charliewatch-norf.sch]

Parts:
K1: TS-1188E; SW4-SMD-7.0X3.5X3.5MM-90D
L1: R-EU_R0603; R0603
LED0, LED1, LED2, LED3, LED4, LED5, LED6, LED7, LED8, LED9, LED10, LED11, LED12, LED13, LED14, LED15, LED16, LED17, LED18, LED19, LED20, LED21, LED22, LED23, LED24, LED25, LED26, LED27, LED28, LED29, LED30, LED31, LED32, LED33, LED34, LED35, LED36, LED37, LED38, LED39, LED40, LED41, LED42, LED43, LED44, LED45, LED46, LED47, LED48, LED49, LED50, LED51, LED52, LED53, LED54, LED55, LED56, LED57, LED58, LED59, LED60, LED61, LED62, LED63, LED64, LED65, LED66, LED67, LED68, LED69, LED70, LED71: LEDCHIPLED_0603; CHIPLED_0603
R1: 75k; R0402
TP1: PTR1TP10SQ; TP10SQ
TP2, TP3, TP4, TP5, TP6: PTR1TP10R; TP10R
U2: CC430F5137IRGZR; QFN50P700X700X100-49N
U$1: CR2032SMT; CR2032-SMD
X1: CRYSTALS-NOGND-IQXC-25; 2.0X1.2-2PAD

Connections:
AVCC: L1.1, U2.27 (AVCC_RF_4), U2.28 (AVCC_RF), U2.31 (AVCC_RF_2), U2.32 (AVCC_RF_3), U2.34 (GUARD)
B0: LED0.A, LED1.A, LED2.A, LED3.A, LED4.A, LED5.A, LED6.A, LED7.A, LED8.C, LED16.C, LED24.C, LED32.C, LED40.C, LED48.C, LED56.C, LED64.C, U2.21 (P3.0/PM_CBOUT0/PM_TA0CLK)
B1: LED0.C, LED8.A, LED9.A, LED10.A, LED11.A, LED12.A, LED13.A, LED14.A, LED15.A, LED17.C, LED25.C, LED33.C, LED41.C, LED49.C, LED57.C, LED65.C, U2.20 (P3.1/PM_TA0CCR0A)
B2: LED1.C, LED9.C, LED16.A, LED17.A, LED18.A, LED19.A, LED20.A, LED21.A, LED22.A, LED23.A, LED26.C, LED34.C, LED42.C, LED50.C, LED58.C, LED66.C, U2.19 (P3.2/PM_TA0CCR1A)
B3: LED2.C, LED10.C, LED18.C, LED24.A, LED25.A, LED26.A, LED27.A, LED28.A, LED29.A, LED30.A, LED31.A, LED35.C, LED43.C, LED51.C, LED59.C, LED67.C, U2.18 (P3.3/PM_TA0CCR2A)
B4: LED3.C, LED11.C, LED19.C, LED27.C, LED32.A, LED33.A, LED34.A, LED35.A, LED36.A, LED37.A, LED38.A, LED39.A, LED44.C, LED52.C, LED60.C, LED68.C, U2.17 (P3.4/PM_TA0CCR3A)
B5: LED4.C, LED12.C, LED20.C, LED28.C, LED36.C, LED40.A, LED41.A, LED42.A, LED43.A, LED44.A, LED45.A, LED46.A, LED47.A, LED53.C, LED61.C, LED69.C, U2.3 (P2.0/PM_CBOUT1/PM_TA1CLK/CB0/A0)
B6: LED5.C, LED13.C, LED21.C, LED29.C, LED37.C, LED45.C, LED48.A, LED49.A, LED50.A, LED51.A, LED52.A, LED53.A, LED54.A, LED55.A, LED62.C, LED70.C, U2.2 (P2.1/PM_TA1CCR0A/CB1/A1)
B7: LED6.C, LED14.C, LED22.C, LED30.C, LED38.C, LED46.C, LED54.C, LED56.A, LED57.A, LED58.A, LED59.A, LED60.A, LED61.A, LED62.A, LED63.A, LED71.C, U2.1 (P2.2/PM_TA1CCR1A/CB2/A2)
B8: LED7.C, LED15.C, LED23.C, LED31.C, LED39.C, LED47.C, LED55.C, LED63.C, LED64.A, LED65.A, LED66.A, LED67.A, LED68.A, LED69.A, LED70.A, LED71.A, U2.48 (P2.3/PM_TA1CCR2A/CB3/A3)
BSL_RST: R1.1, TP6.TP, U2.40 (~RST/NMI/SBWTDIO)
BSL_RX: TP3.TP, U2.6 (P1.5/PM_UCA0RXD/PM_UCA0SOMI)
BSL_TEST: TP5.TP, U2.39 (TEST/SBWTCK)
BSL_TX: TP4.TP, U2.5 (P1.6/PM_UCA0TXD/PM_UCA0SIMO)
BSL_VCC: TP2.TP, U2.8 (DVCC_2)
BUTTON: K1.2, U2.4 (P1.7/PM_UCA0CLK/PM_UCB0STE)
DVCC_3: U2.22 (DVCC_3)
GND: K1.1, TP1.TP, U2.42 (AVSS), U2.49 (EP), U$1.-
P2.4: U2.47 (P2.4/PM_RTCCLK/CB4/A4/VREF-/VEREF-)
P2.7: U2.23 (P2.7/PM_ADC12CLK/PM_DMAE0)
P3.5: U2.16 (P3.5/PM_TA0CCR4A)
P3.6: U2.15 (P3.6/PM_RFGDO1)
P3.7: U2.14 (P3.7/PM_SMCLK)
RF_N: U2.30 (RF_N)
RF_P: U2.29 (RF_P)
RF_XIN: U2.25 (RF_XIN)
RF_XOUT: U2.26 (RF_XOUT)
R_BIAS: U2.33 (R_BIAS)
VCC: L1.2, R1.2, U2.41 (DVCC), U2.45 (AVCC), U$1.+$1 (+)
VCORE: U2.7 (VCORE)
XIN: U2.44 (P5.0/XIN), X1.2
XOUT: U2.43 (P5.1/XOUT), X1.1

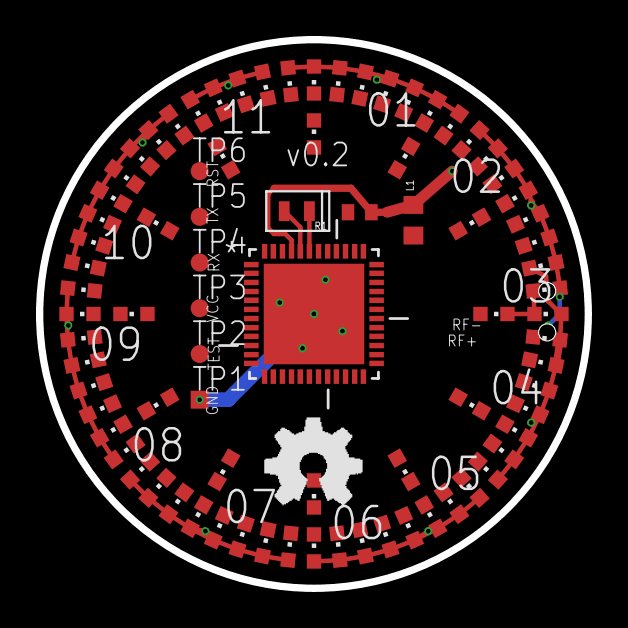
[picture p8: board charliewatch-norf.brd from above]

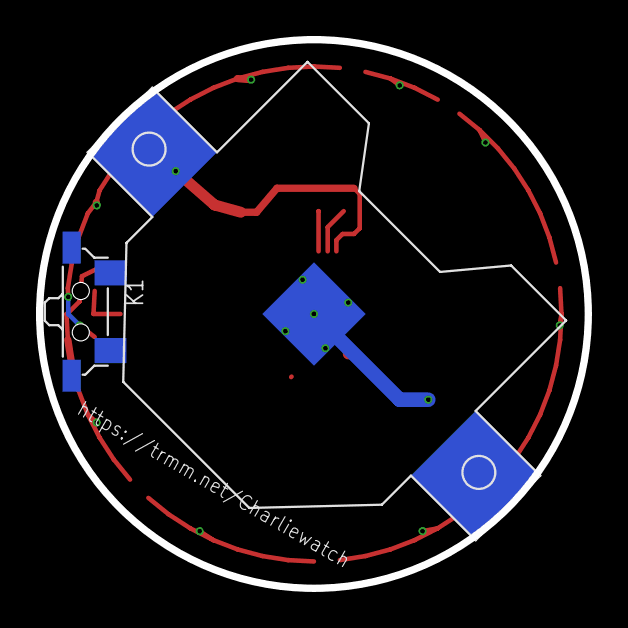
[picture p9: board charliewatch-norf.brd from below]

Board: 2 copper layers, 30.5 x 30.5 mm, 84 parts (2 on the bottom side), 20 nets.

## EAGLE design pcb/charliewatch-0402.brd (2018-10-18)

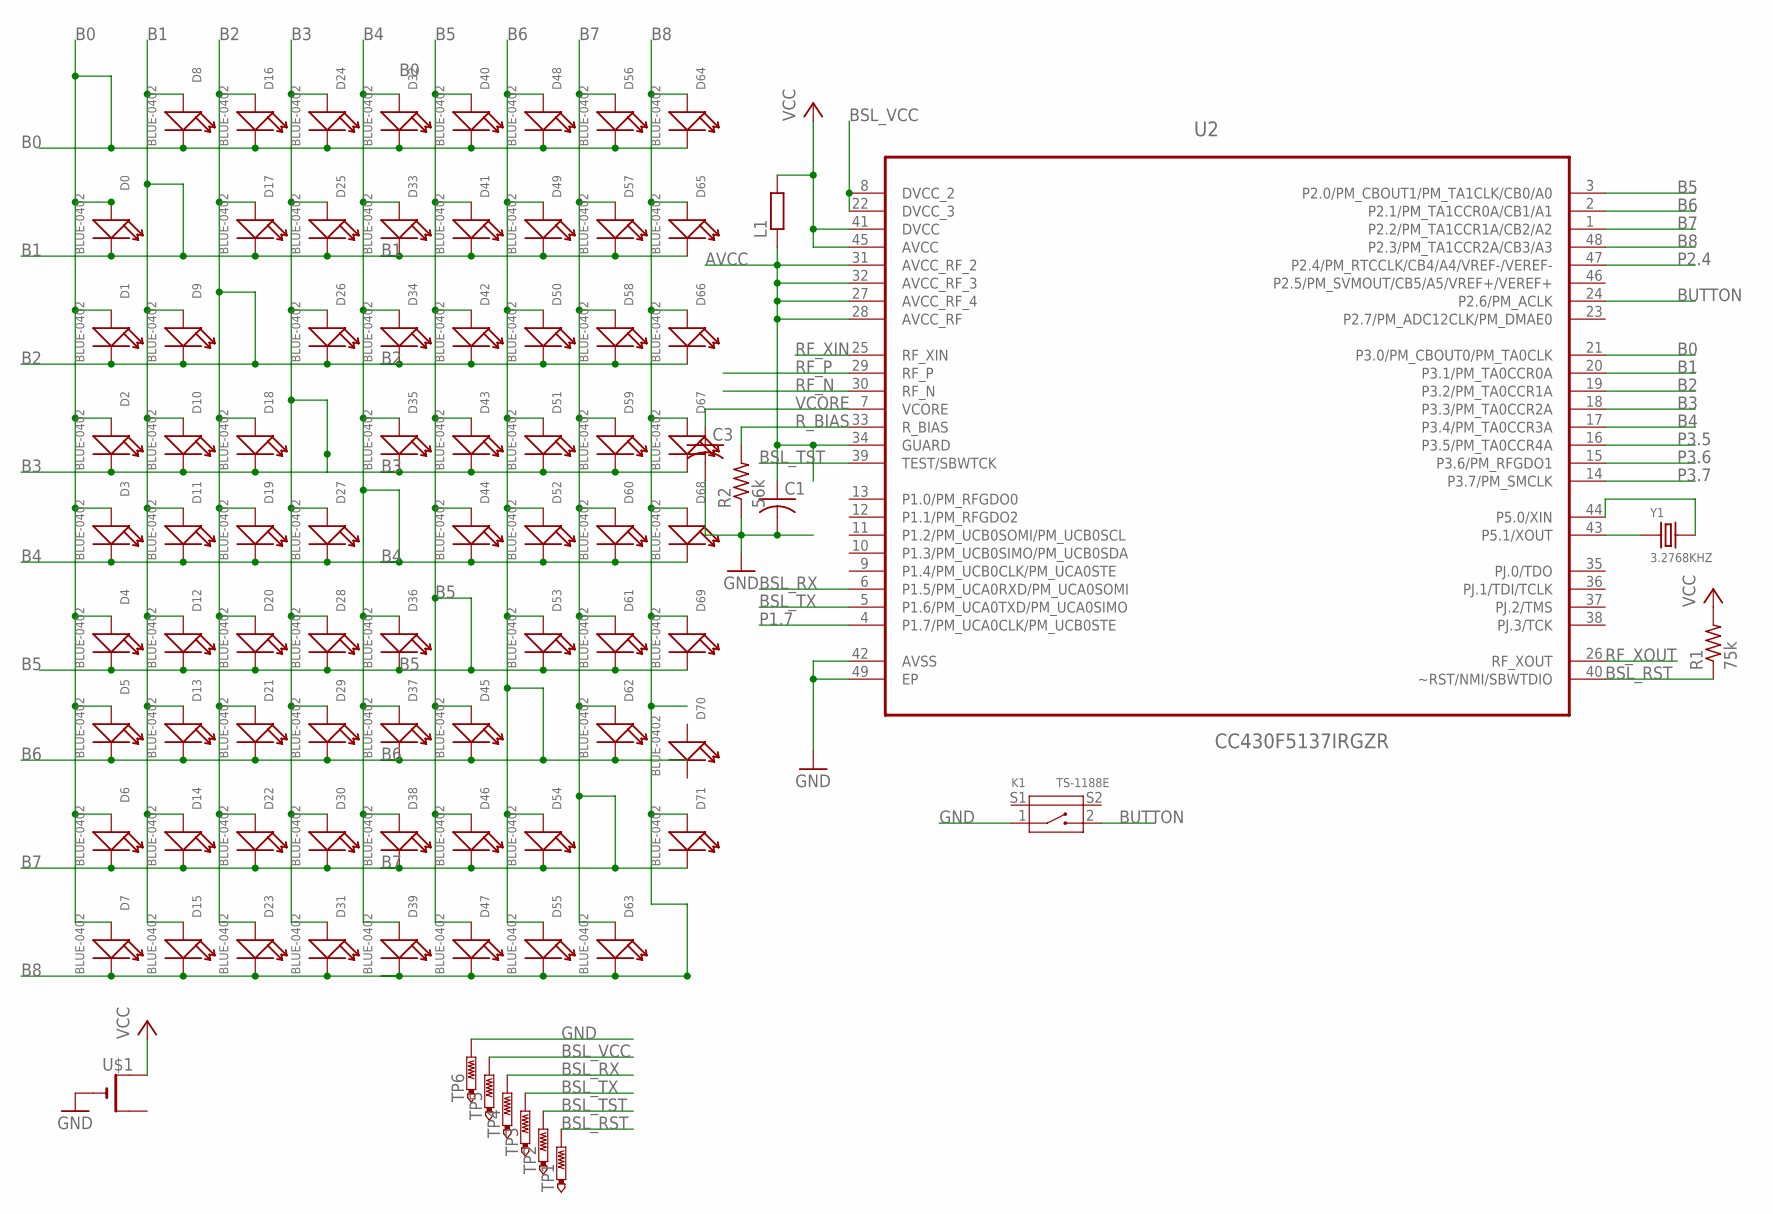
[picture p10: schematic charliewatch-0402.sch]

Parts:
C1, C3: C-USC0402; C0402
D0, D1, D2, D3, D4, D5, D6, D7, D8, D9, D10, D11, D12, D13, D14, D15, D16, D17, D18, D19, D20, D21, D22, D23, D24, D25, D26, D27, D28, D29, D30, D31, D32, D33, D34, D35, D36, D37, D38, D39, D40, D41, D42, D43, D44, D45, D46, D47, D48, D49, D50, D51, D52, D53, D54, D55, D56, D57, D58, D59, D60, D61, D62, D63, D64, D65, D66, D67, D68, D69, D70, D71: BLUE-0402; LED-0402
K1: TS-1188E; SW4-SMD-7.0X3.5X3.5MM-90D
L1: R-EU_R0603; R0603
R1: 75k; R0402
R2: 56k; R0402
TP1, TP2, TP3, TP4, TP5: PTR1TP10R; TP10R
TP6: PTR1TP10SQ; TP10SQ
U2: CC430F5137IRGZR; QFN50P700X700X100-49N
U$1: CR2032SMT; CR2032-SMD
Y1: 3.2768KHZ; X2-SMD-L2.0X1.2X0.55MM

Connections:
AVCC: C1.1, L1.1, U2.27 (AVCC_RF_4), U2.28 (AVCC_RF), U2.31 (AVCC_RF_2), U2.32 (AVCC_RF_3), U2.34 (GUARD)
B0: D0.+, D1.+, D2.+, D3.+, D4.+, D5.+, D6.+, D7.+, D8.-, D16.-, D24.-, D32.-, D40.-, D48.-, D56.-, D64.-, U2.21 (P3.0/PM_CBOUT0/PM_TA0CLK)
B1: D0.-, D8.+, D9.+, D10.+, D11.+, D12.+, D13.+, D14.+, D15.+, D17.-, D25.-, D33.-, D41.-, D49.-, D57.-, D65.-, U2.20 (P3.1/PM_TA0CCR0A)
B2: D1.-, D9.-, D16.+, D17.+, D18.+, D19.+, D20.+, D21.+, D22.+, D23.+, D26.-, D34.-, D42.-, D50.-, D58.-, D66.-, U2.19 (P3.2/PM_TA0CCR1A)
B3: D2.-, D10.-, D18.-, D24.+, D25.+, D26.+, D27.+, D28.+, D29.+, D30.+, D31.+, D35.-, D43.-, D51.-, D59.-, D67.-, U2.18 (P3.3/PM_TA0CCR2A)
B4: D3.-, D11.-, D19.-, D27.-, D32.+, D33.+, D34.+, D35.+, D36.+, D37.+, D38.+, D39.+, D44.-, D52.-, D60.-, D68.-, U2.17 (P3.4/PM_TA0CCR3A)
B5: D4.-, D12.-, D20.-, D28.-, D36.-, D40.+, D41.+, D42.+, D43.+, D44.+, D45.+, D46.+, D47.+, D53.-, D61.-, D69.-, U2.3 (P2.0/PM_CBOUT1/PM_TA1CLK/CB0/A0)
B6: D5.-, D13.-, D21.-, D29.-, D37.-, D45.-, D48.+, D49.+, D50.+, D51.+, D52.+, D53.+, D54.+, D55.+, D62.-, U2.2 (P2.1/PM_TA1CCR0A/CB1/A1)
B7: D6.-, D14.-, D22.-, D30.-, D38.-, D46.-, D54.-, D56.+, D57.+, D58.+, D59.+, D60.+, D61.+, D62.+, D63.+, D71.-, U2.1 (P2.2/PM_TA1CCR1A/CB2/A2)
B8: D7.-, D15.-, D23.-, D31.-, D39.-, D47.-, D55.-, D63.-, D64.+, D65.+, D66.+, D67.+, D68.+, D69.+, D71.+, U2.48 (P2.3/PM_TA1CCR2A/CB3/A3)
BSL_RST: R1.1, TP1.TP, U2.40 (~RST/NMI/SBWTDIO)
BSL_RX: TP4.TP, U2.6 (P1.5/PM_UCA0RXD/PM_UCA0SOMI)
BSL_TST: TP2.TP, U2.39 (TEST/SBWTCK)
BSL_TX: TP3.TP, U2.5 (P1.6/PM_UCA0TXD/PM_UCA0SIMO)
BSL_VCC: TP5.TP, U2.8 (DVCC_2), U2.22 (DVCC_3)
BUTTON: K1.2, U2.24 (P2.6/PM_ACLK)
GND: C1.2, C3.2, K1.1, R2.1, TP6.TP, U2.42 (AVSS), U2.49 (EP), U$1.-
P1.7: U2.4 (P1.7/PM_UCA0CLK/PM_UCB0STE)
P2.4: U2.47 (P2.4/PM_RTCCLK/CB4/A4/VREF-/VEREF-)
P3.5: U2.16 (P3.5/PM_TA0CCR4A)
P3.6: U2.15 (P3.6/PM_RFGDO1)
P3.7: U2.14 (P3.7/PM_SMCLK)
RF_N: U2.30 (RF_N)
RF_P: U2.29 (RF_P)
RF_XIN: U2.25 (RF_XIN)
RF_XOUT: U2.26 (RF_XOUT)
R_BIAS: R2.2, U2.33 (R_BIAS)
VCC: L1.2, R1.2, U2.41 (DVCC), U2.45 (AVCC), U$1.+$1 (+)
VCORE: C3.1, U2.7 (VCORE)
XIN: U2.44 (P5.0/XIN), Y1.2
XOUT: U2.43 (P5.1/XOUT), Y1.1

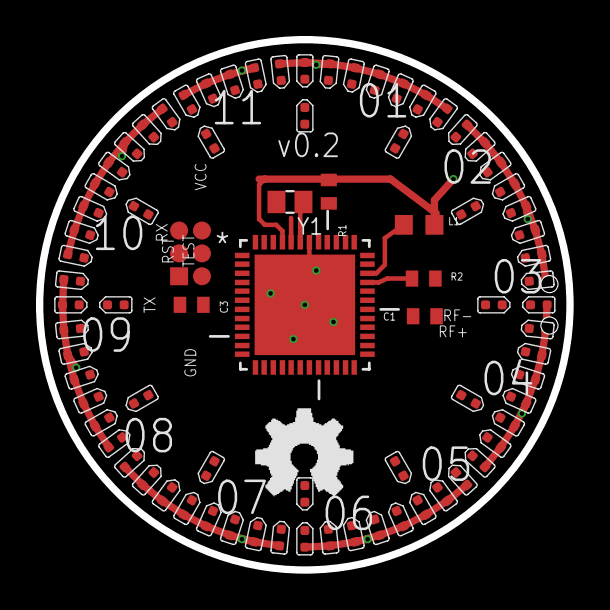
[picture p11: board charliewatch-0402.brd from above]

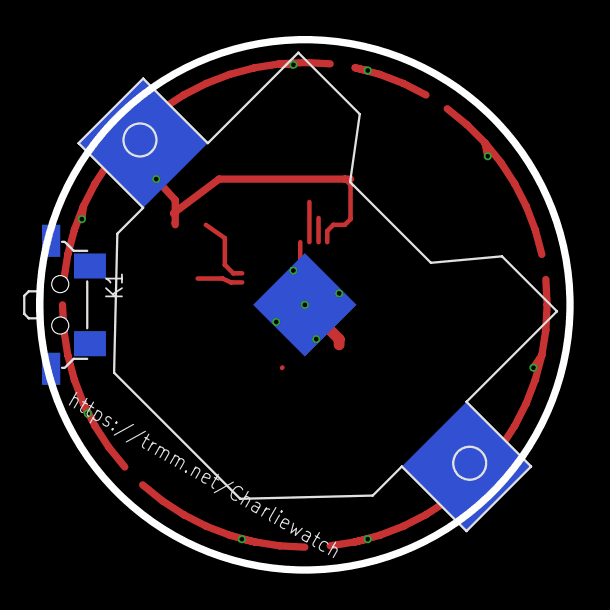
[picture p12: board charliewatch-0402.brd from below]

Board: 2 copper layers, 29.5 x 29.5 mm, 87 parts (2 on the bottom side), 22 nets.

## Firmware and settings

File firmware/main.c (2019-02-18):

/*! \file main.c

  \brief Main module.  This version initializes the hardware and then
   drops to a low power mode, letting the WDT update the LEDs every 16ms

  Schematic and more at https://trmm.net/Charliewatch
*/

#include <msp430.h>
#include <string.h>
#include <stdio.h>
#include <stdlib.h>

#include "rtc.h"
#include "ucs.h"
#include "led.h"
#include "adc.h"
#include "power.h"
#include "button.h"

//! Activates and configures the module, but does not turn on reference.
void ref_init(){
  //Setting the master bit disables legacy mode.
  REFCTL0|=REFMSTR;

  //Wait for register to not be busy before modifying voltage.
  while(REFCTL0 & REFGENBUSY);
  
  //2.5V reference.
  REFCTL0 &= ~BGMODE;
  REFCTL0|=REFVSEL_2;
}


//! Main method.
int main(void)
{
	WDTCTL = WDTPW + WDTHOLD; // Stop WDT

	ref_init();
	//uart_init();

	// drive port J and 1 to ground to avoid CMOS power drain
	PJDIR |=  0xF;
	PJOUT &= ~0xF;
	P1DIR |=  0xF;
	P1OUT &= ~0xF;

	button_init();

	// turn off all the LEDs to reduce power
	led_off();

#if 1
	led_test();
#else
	while(1) {
		led_test();
		delay(1000);
	}
#endif

	rtc_init();
	ucs_init(); // doesn't work if crystal isn't there?

	// Setup and enable WDT 16ms, ACLK, interval timer
	WDTCTL = WDT_ADLY_16;
	SFRIE1 |= WDTIE;

	// go into low power mode
	power_setvcore(0);
	ucs_slow();

	__bis_SR_register(LPM3_bits + GIE);        // Enter LPM3

	// flash the 0 hour so that we know something is wrong
	while(1)
	{
		led_on(60); delay(1);
		led_off(); delay(3);
		led_on(60); delay(1);
		led_off(); delay(6);
	}
}


extern void stopwatch_draw(void);
extern void clockset_draw(void);
extern void animation_draw(void);

static void voltage_draw(void)
{
	unsigned i;
	unsigned raw_volts = adc12_single_conversion(
		REFVSEL_1, ADC12SHT0_10, ADC12INCH_11);


#if 0
	static unsigned bright = 0;
	bright = (bright + 1) % 128;

	for(i = 0 ; i < 12 ; i++)
	{
		if (0 == (raw_volts & (1<<i)))
			continue;
		led_dither(60+i, bright > 64 ? 128 - bright : bright);
	}

	unsigned scaled = raw_volts / 68;
	for(i = 0 ; i < scaled ; i++)
	{
		led_on(i);
	}
#else
	unsigned millivolts = (1250 * (uint32_t) raw_volts) / 1024;
	led_on(60 + (millivolts / 1000));

	unsigned mv = ((millivolts % 1000) * 60) / 1000;
	for(i = 0 ; i < mv ; i++)
	{
		led_on(i);
	}
#endif
		
	led_off();
}

static void (*const modes[])(void) = {
	//voltage_draw,
	animation_draw,
	stopwatch_draw,
	clockset_draw,
	clockset_draw,
	voltage_draw,
};

static const unsigned mode_count = sizeof(modes) / sizeof(*modes);
unsigned watch_mode = 0;


//! Watchdog Timer interrupt service routine, calls back to handler functions.
void __attribute__ ((interrupt(WDT_VECTOR)))
watchdog_timer(void)
{
	ucs_fast();

	button_update();

	// long hold advances mode
	if (button_long)
		watch_mode = (watch_mode + 1) % mode_count;

	modes[watch_mode]();

	led_off();
	ucs_slow();
}

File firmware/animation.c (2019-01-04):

/*! \file animation.c

  \brief Drawing functions based on the time.

Animations are drawn:
* When the second hand hits the minute hand
* When the second hand hits the minute hand on a 5 minut emark
* When the second hand hits the hour hand
* When all three hands line up
* At midnight/noon
*/

#include <msp430.h>
#include <string.h>
#include <stdio.h>
#include <stdlib.h>

#include "led.h"

void delay(unsigned len)
{
#if 0
	const uint8_t p2 = P2OUT;
	const uint8_t p3 = P3OUT;

	while(len)
	{
		// toggle the LEDs back on
		P2OUT = p2;
		P3OUT = p3;
		len--;

		// now toggle them off
		P2OUT = 0;
		P3OUT = 0;
	}
#else
	len *= 2;
	while(len)
	{
		asm("");
		len--;
	}
#endif
}


// In normal operation there are four LEDs powered on
// The minute is full bright
// The hour is half bright
// the second is quarter bright
// the previous second fades
uint8_t led_display[] = {};
uint8_t led_bright[] = {};


void led_draw(void)
{
	int i;

	for(i=0 ; i < NUM_DISPLAY ; i++)
	{
		const unsigned led = led_display[i];
		const unsigned bright = led_bright[i];

#if 0
		if (bright > 0)
			led_on(led);

		if (bright > 1)
			delay(bright);
		else
			led_off();
#else
		led_dither(led, bright);
#endif
	}

	led_off();
}


static unsigned animation_counter = 0;
static void (*animation)(unsigned counter) = NULL;

static void sparkle_animation(unsigned count)
{
#if 0
	// should make the sparkles converge inward
	led_on((RTCSEC + rand() % (count/8) - count/16 + 240) % 60);
	led_on((RTCMIN + rand() % (count/8) - count/16 + 240) % 60);
	led_on((RTCHOUR*5 + rand() % (count/8) - count/16 + 240) % 60);
	led_on(rand() % 60);
	led_on(60 + (rand() % 12));
#else
	unsigned i;
	if (count > 72)
		count = 12;
	else
		count /= 8;

	for(i = 0 ; i < count ; i++)
		led_on(rand() % 72);

	// start turning on the hands
	if (count < 20)
	{
		led_on(led_display[0]);
		led_on(led_display[1]);
		led_on(RTCSEC);
	}
#endif
}

// animation 1 for when all the hands align
static void align_animation(unsigned count)
{
	unsigned i;

	if (count > 180)
	{
		// draw out from the minute up to the count
		for(i=0 ; i < 240 - count ; i++)
			led_on((RTCMIN + i + 60) % 60);

		// draw out from the hour hand in reverse
		for(i=0 ; i < (240 - count)/5 ; i ++)
			led_on(60 + (RTCHOUR + i + 12) % 12);
	} else
	if (count > 120)
	{
		// start collapsing back to the minute
		for(i= 0 ; i < count - 120 ; i++)
			led_on((RTCMIN - i + 60) % 60);

		// collapse back to the hour hand
		for(i=0 ; i <= (count - 120)/5 ; i ++)
			led_on(60 + (RTCHOUR - i + 12) % 12);
	} else
	if (count > 60)
	{
		// draw out from the minute up to the count
		for(i=0 ; i < 120 - count ; i++)
			led_on((RTCMIN - i + 60) % 60);

		// draw out from the hour hand in reverse
		for(i=0 ; i <= (120 - count)/5 ; i ++)
			led_on(60 + (RTCHOUR + i + 12) % 12);
	} else {
		// start collapsing back to the minute
		for(i= 0 ; i < count ; i++)
			led_on((RTCMIN + i + 60) % 60);

		// collapse back to the hour hand
		for(i=0 ; i <= count/5 ; i ++)
			led_on(60 + (RTCHOUR - i + 12) % 12);
	}
}

// animation 2 for when all the hands align
static void race_animation(unsigned count)
{
	// second hand races at full speed
	led_display[2] = (RTCMIN + 360 - count) % 60;

	// minute hand at half speed
	led_display[0] = (RTCMIN + 360 - count/2) % 60;

	// hour hand at 1/3 speed
	led_display[1] = (RTCMIN + 360 - count/3) % 60;

	led_draw();
}

// animation for when the hands align at 3 and 9
// rotate start at max speed, rotate stop at half speed,
// makes four revolutions
// count goes from 240 to 0
static void chase_animation(unsigned count)
{
	unsigned i;

	// change the sense of the count
	count = 240 - count;

	if (count < 120)
	{
		// first two laps (0-59), go from slow to fast
		// at the end the entire watch is illuminated
		for(i = count/2 ; i < count ; i++)
			led_on((i + RTCSEC) % 60);
	} else {
		// second two laps, go from fast to slow, undrawing
		// at the end nothing is illuminated
		count -= 120;
		for(i = count ; i < count/2 + 60 ; i++)
			led_on((i + RTCSEC) % 60);
	}

	led_off();
}

// when the second hand lines up with the hour and the minute
// is 180 degrees away
static void opposite_animation(unsigned count)
{
	unsigned i;

	if (count >= 60)
	{
		// grow the bargraph between the two points until they meet
		count = (120 - count) / 2;
		for(i = 0 ; i < count ; i++)
		{
			led_on((RTCSEC + i) % 60);
			led_on((RTCMIN + i) % 60);
		}
	} else
	{
		// retract the bargraph between the two
		count /= 2;
		for(i = 0 ; i <= count ; i++)
		{
			led_on((RTCSEC - i + 60) % 60);
			led_on((RTCMIN - i + 60) % 60);
		}
	}

	// and keep the actual hour on
	led_on(led_display[1]);
}

// rotate all three together
static void triangle_animation(unsigned count)
{
	const unsigned hour = (RTCHOUR % 12) * 5;
	unsigned i;

	if (RTCSEC < RTCMIN)
	{
		// spin all three around twice
		led_on((RTCSEC + 120 - count) % 60);
		led_on((RTCMIN + 120 - count) % 60);
		led_on((hour + 120 - count) % 60);

	} else
	if (count >= 60)
	{
		// grow the bargraph between the three points
		// count goes from 0 - 20
		count = (120 - count) / 3;
		for(i = 0 ; i < count ; i++)
		{
			led_dither((RTCSEC + i) % 60, (20 - count + i)/8);
			led_dither((RTCMIN + i) % 60, (20 - count + i)/8);
			led_dither((hour + i) % 60, (20 - count + i)/8);
		}
	} else
	{
		// retract the bargraph to the three
		// count goes from 20 to 0
		count /= 3;
		for(i = 0 ; i <= count ; i++)
		{
			led_dither((RTCSEC - i + 60) % 60, (count - i)/8);
			led_dither((RTCMIN - i + 60) % 60, (count - i)/8);
			led_dither((hour - i + 60) % 60, (count - i)/8);
		}
	}

	// and keep the actual hour on
	led_on(led_display[1]);
}

static void hour_animation(unsigned count)
{
	// run the hour backwards
	if (3 == (count % 5))
		led_display[1] = 60 + (led_display[1] - 60 - 1 + 12) % 12;

	// and the second hand should match it
	led_display[2] = (led_display[2] + 1) % 60;

	led_draw();
}


static void minute_animation(unsigned count)
{
	// run the minute hand backwards at half speed
	if (0 == (count & 1))
		led_display[0] = (led_display[0] + 60 - 1) % 60;

	// run the second hand forward at full speed
	led_display[2] = (led_display[2] + 1) % 60;

	// if this occured at the start of a new hour,
	// run an hour hand animation, too
	if (RTCMIN == 0 && (count % 5) == 0)
		led_display[1] = 60 + (led_display[1] - 60 - 1 + 12) % 12;

	led_draw();
}

// count will be start at 60
static void new_minute_animation(unsigned count)
{
	// if earlier than 30 minute past the hour,
	//	run the hand forwards to 59
	// otherwise
	//	run the hard backwards to 1
	// reset animation counter when we hit either condition

	if (RTCMIN > 30)
		count = RTCMIN + count - 60;
	else
		count = RTCMIN - count + 60;

	if (count == 0 || count == 59)
		animation_counter = 0;

	led_on(count);
	led_off();

	// ensure that the second hand advances
	led_display[2] = RTCSEC;

	led_draw();
}
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

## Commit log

2018-09-27 v0 board autoroutes 100%
    [charliewatch.brd, charliewatch.sch, routed.brd]
2018-09-27 fixed drc errors, one missing vcc pin
    [charliewatch.sch]
2018-09-27 move labels and 1x6 around; issues with the additional vcc line
    [charliewatch.brd, routed.brd]
2018-09-27 replace with "1x6 lock" part
    [charliewatch.brd, charliewatch.sch, routed.brd]
2018-09-27 tweaked text, added oshw logo
    [charliewatch.brd, routed.brd]
2018-09-27 as orderd v0.1
    [charliewatch.brd, routed.brd]
2018-09-28 ignore routed schematic, which sould not be checked in
2018-09-28 v0.1 schematic
2018-10-13 blink all the led test
2018-10-13 pwm brightness works
2018-10-13 move LED code into separate file
2018-10-13 programming cable note
2018-10-13 Simple 3d printed case for testing
    [case.scad]
2018-10-13 make the case fit a CR2405 battery holder
    [case.scad]
2018-10-13 ignore STL files
2018-10-15 try using power_setvcore() to bring the internal voltage down to svae power
2018-10-15 energy trace notes
2018-10-15 switch hour animation direction
2018-10-16 turn off P1 to reduce even more current draw (less than 10 uA with the LEDs off)
2018-10-16 ensure that the LEDs are off before going to sleep
2018-10-17 experimenting with temporal dithering on LEDs
2018-10-18 0402 sized LEDs
    [charliewatch-0402.brd, charliewatch-0402.sch]
2018-10-18 press-fit watch face from the back
    [case.scad]
2018-10-19 no rf variant (routable)
    [charliewatch-norf.brd, charliewatch-norf.sch]
2018-10-19 slightly smaller, still routable version with no RF components
    [charliewatch-norf.brd]
2018-10-20 routed version of the no-rf variant, with 1 square inch of board area
    [charliewatch-norf.sch, routed-norf.brd]
2018-10-21 button configuration and stop/reset logic works
    [main.c]
2018-10-22 fix off by one blink in opposite and triangle time
    [animation.c]
2018-10-26 sweep second hour during hour/second alignment (issue #3)
    [animation.c]
2018-10-26 make the all align animation run twice (issue #4)
    [animation.c]
2018-10-26 new minute animation (issue #2)
    [animation.c]
2018-10-26 special all align animation for six (issue #4)
    [animation.c]
2018-10-27 improve new minute animation by rewinding minute hand (issue #2)
    [animation.c]
2018-10-27 improve new minute animation by rewinding or forwarding minute hand (issue #2)
    [animation.c]
2018-10-28 v0.2 case for the smaller watch face
    [case.scad]
2018-10-29 stencil for v0.2 board (no RF components, smaller diameter)
2018-10-29 outline and alignment holes
2018-10-30 local variable for led
2018-10-30 led_dither() to reduce power, improve brightness control
2018-11-03 make band size an option
    [case.scad]
2018-11-04 images of the two board versions
2018-11-04 change the brightness for different LEDs
2018-11-04 fix led test to finish sooner
    [main.c]
2018-11-04 make button support v0.2 boards
2018-11-11 started on band design
    [case.scad]
2018-11-11 larger pieces for the strap, sizing gauge
    [case.scad]
2018-11-11 round off the case
    [case.scad]
2018-11-12 smooth out the bands a bit more
    [case.scad]
2018-11-12 full band and case works for rev 0.2 boards
    [case.scad]
2018-11-12 measure battery voltage and draw a bar graph
2018-11-13 taper the band
    [case.scad]
2018-11-13 fix spacing on lug
    [case.scad]
2018-11-22 v0.2 nato strap version (18mm) with sapphire
    [case.scad]
2019-01-04 switch hour hand direction in hour/second crossing
2019-01-04 as ordered from dirtypcb
    [routed-norf.brd]
2019-02-18 fix pins for avoiding power drain
    [main.c]
2019-05-18 started on 0603 bicolor version
    [charliewatch-bicolor.brd, charliewatch-bicolor.sch]
2019-05-18 initial positioning for the bicolor leds
    [charliewatch-bicolor.brd, charliewatch-bicolor.sch]
2019-05-19 change to through-hole cr2032 and hack up the layout
    [charliewatch-bicolor.brd, charliewatch-bicolor.sch]

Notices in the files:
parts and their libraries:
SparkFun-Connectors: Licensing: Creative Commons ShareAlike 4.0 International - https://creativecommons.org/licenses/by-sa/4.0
